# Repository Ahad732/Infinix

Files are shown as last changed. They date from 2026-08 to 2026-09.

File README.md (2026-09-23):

# Infinix
Infinix is a split keyboard that's wireless and runs on bluetooth. It works on a battery which keeps it being portable and being convenient. It also has a RGB underglow which makes it look pretty good. It runs on the ZMK firmware. It can be assembled easily using a simple soldering iron by soldering the XIAO directly on the board and the rest of the diodes and the leds and finally the switches and flashing the firmware, dont forget the batteries and their terminals.

| |Footprint |Value |Quantity |Price |Link |
|---|---|---|---|---|---|
|C1, C2 |CP_Elec_10x10 |1 mF |3 |0.28  |https://robu.in/product/efvm016ada102m10b0-follon-1000uf-25v-10xl10-5mm-aluminum-electrolytic-capacitors-smd-rohs/ |
|D1 - D42  |D_SOD-123 |D |50 |0.5 |https://robu.in/product/sm4007pl-a7-slkor-1a-1kv-1-1v1a-sod-123fl-diodes-general-purpose-rohs/ |
|D43 - D84 |MX_SK6812MINI-E |SK6812MINI-E |51 |5.55  |https://www.etstore.in/products/e9974?variant=48993209319675 |
|R1, R2 |603 |806k |30 |0.12  |https://robu.in/product/0603waf8063t5e-uniohm-royal-ohm-100mw-thick-film-resistors |
|R3, R4 |805 |2M |15 |0.11  |https://robu.in/product/ac0805fr-072ml-yageo-res-thick-film-0805-2m-ohm |
|R5, R6 |1206 |330 |100 |0.13  |https://robu.in/product/1206w4j0331t5e-uniohm-royal-ohm-250mw-thick-film-resistors-200v-%c2%b1100ppm-%e2%84%83-%c2%b15-330%cf%89-1206-chip-resistor-surface-mount-roh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|
|SW1 - SW42|SW_Cherry_MX_1.00u_PCB|SW_Push |1 pack of 45  |11.52 |https://stackskb.com/store/akko-v3-lavender-purple-pro-switch-pack-of-45/ |
|U1, U2 |XIAO-nRF52840-SMD |XIAO-nRF52840-SMD|2 |24.06 |https://www.lioncircuits.com/parts/102010448 |
| |Keycaps |103 Key |1 |10.47 |https://www.amazon.in/gp/product/B0GZMBPHYB/ref=ox_sc_act_title_1?smid=A3S55Z3ML7GNN5&psc=1 |
| |Battery |1500 mAh |2 |9.33  |https://robu.in/product/wly103443-1500mah-3-7v-single-cell-rechargeable-lipo-battery/ |
| | | |Parts Shipping|2.93  | |
| | | |PCB |39.33 | |
| | | |Total |104.33| |

3d-model
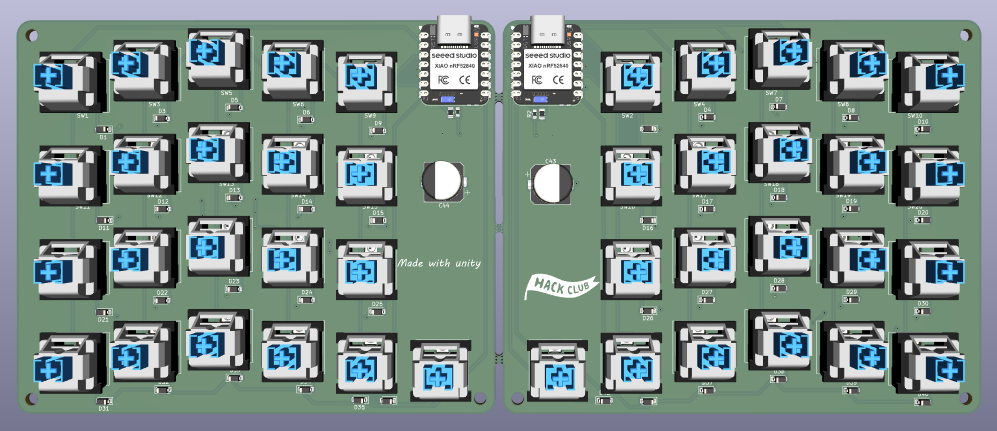
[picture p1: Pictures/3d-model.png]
3d-model
     
PCB
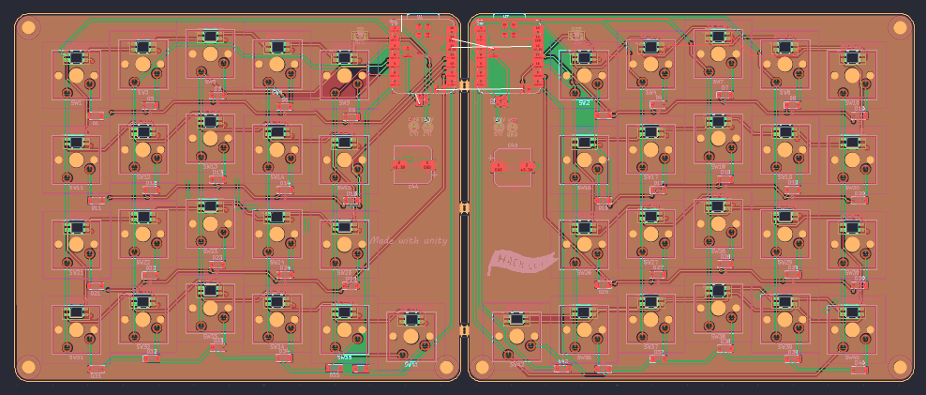
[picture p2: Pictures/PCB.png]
PCB
  
Schematic
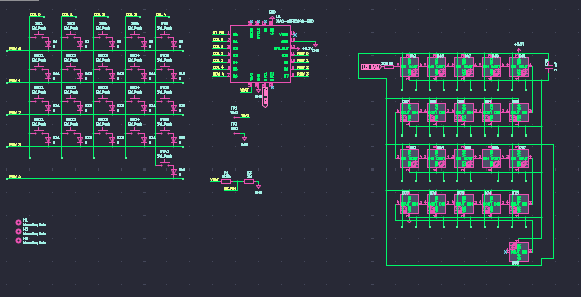
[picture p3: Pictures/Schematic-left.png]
Schematic
  
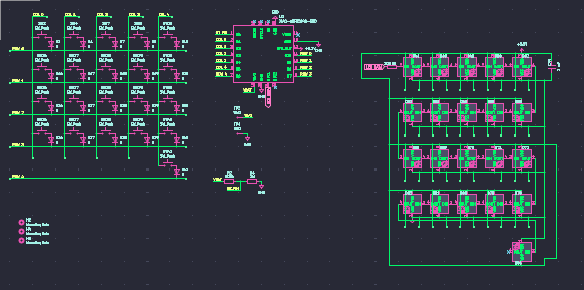
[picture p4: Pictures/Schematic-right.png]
Schematic
  
CAD
CAD
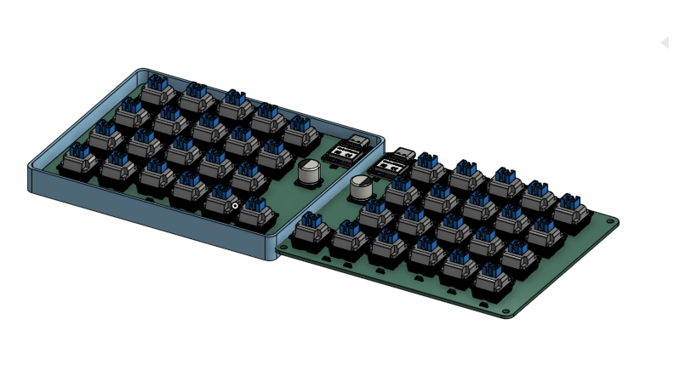
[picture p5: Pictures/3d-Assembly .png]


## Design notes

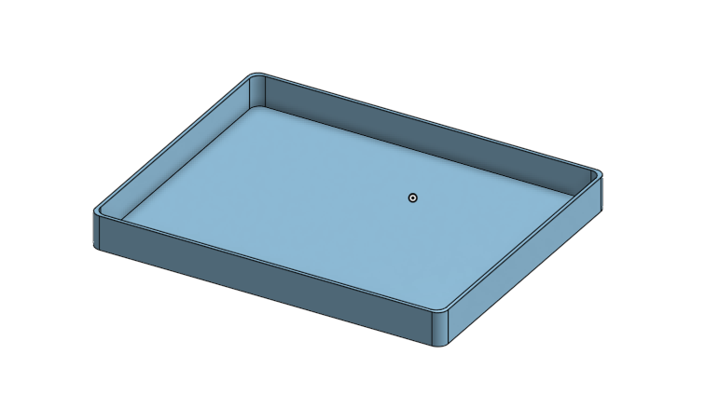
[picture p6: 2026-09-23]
Pictures/Case.png

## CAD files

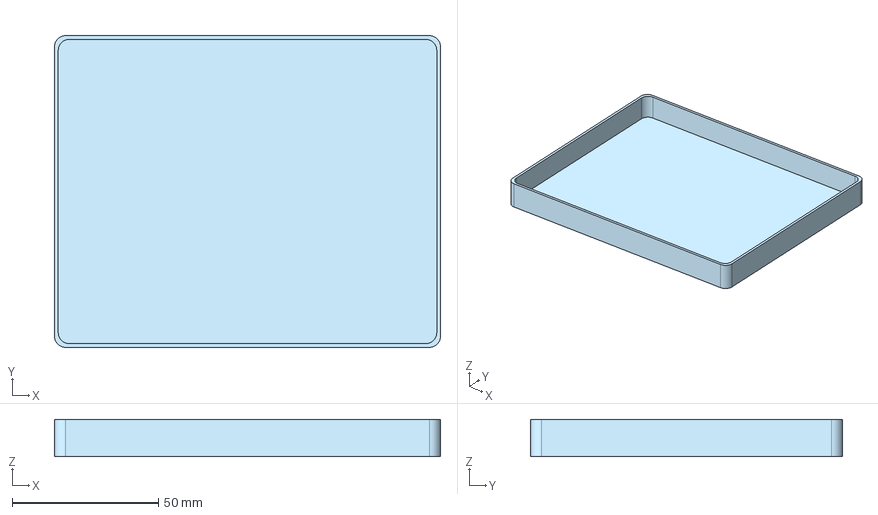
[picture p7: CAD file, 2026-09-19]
CAD/Part Studio 1.step
132.1 x 106.7 x 12.7 mm

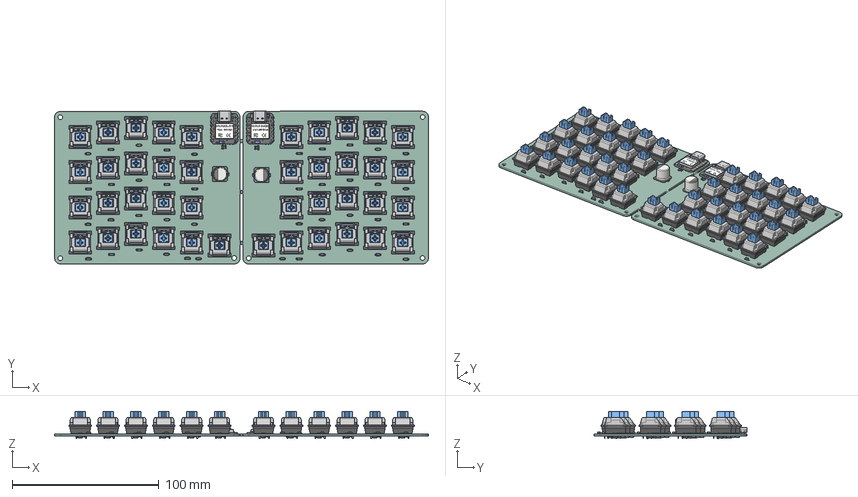
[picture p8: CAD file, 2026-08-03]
CAD/Split Keyboard.step
255.2 x 104.4 x 18.7 mm
Button x 42
Pins x 44
SK6812MINI-E v4 x 42
D_SOD-123 x 42
R_0603_1608Metric x 2
R_0805_2012Metric x 2
CP_Elec_10x10 x 2
BOSS-EXTRUDE14_8_ x 2
BOSS-EXTRUDE7_4_ x 2
BOSS-EXTRUDE7_3_ x 2
BOSS-EXTRUDE14_4_ x 2
BOSS-EXTRUDE14_2_ x 2
BOSS-EXTRUDE14_11_ x 2
BOSS-EXTRUDE7_7_ x 2
BOSS-EXTRUDE14_9_ x 2
BOSS-EXTRUDE14_3_ x 2
BOSS-EXTRUDE14_7_ x 2
MIRROR2 x 2
BOSS-EXTRUDE14_5_ x 2
BOSS-EXTRUDE14_12_ x 2
BOSS-EXTRUDE7_8_ x 2
BOSS-EXTRUDE7_1_ x 2
BOSS-EXTRUDE14_10_ x 2
BOSS-EXTRUDE7_9_ x 2
BOSS-EXTRUDE14_6_ x 2
BOSS-EXTRUDE14_1_ x 2
BOSS-EXTRUDE7_6_ x 2
BOSS-EXTRUDE7_2_ x 2
CUT-EXTRUDE5 x 2
BOSS-EXTRUDE7_5_ x 2
Shield x 2
CAP x 4
ANT1 x 2
Silkscreen x 2
CAP 3 x 2
LED x 2
USR x 2
MSM261D3526H1CPM x 2
R_1206_3216Metric x 2
Split Keyboard_pad
Split Keyboard_PCB

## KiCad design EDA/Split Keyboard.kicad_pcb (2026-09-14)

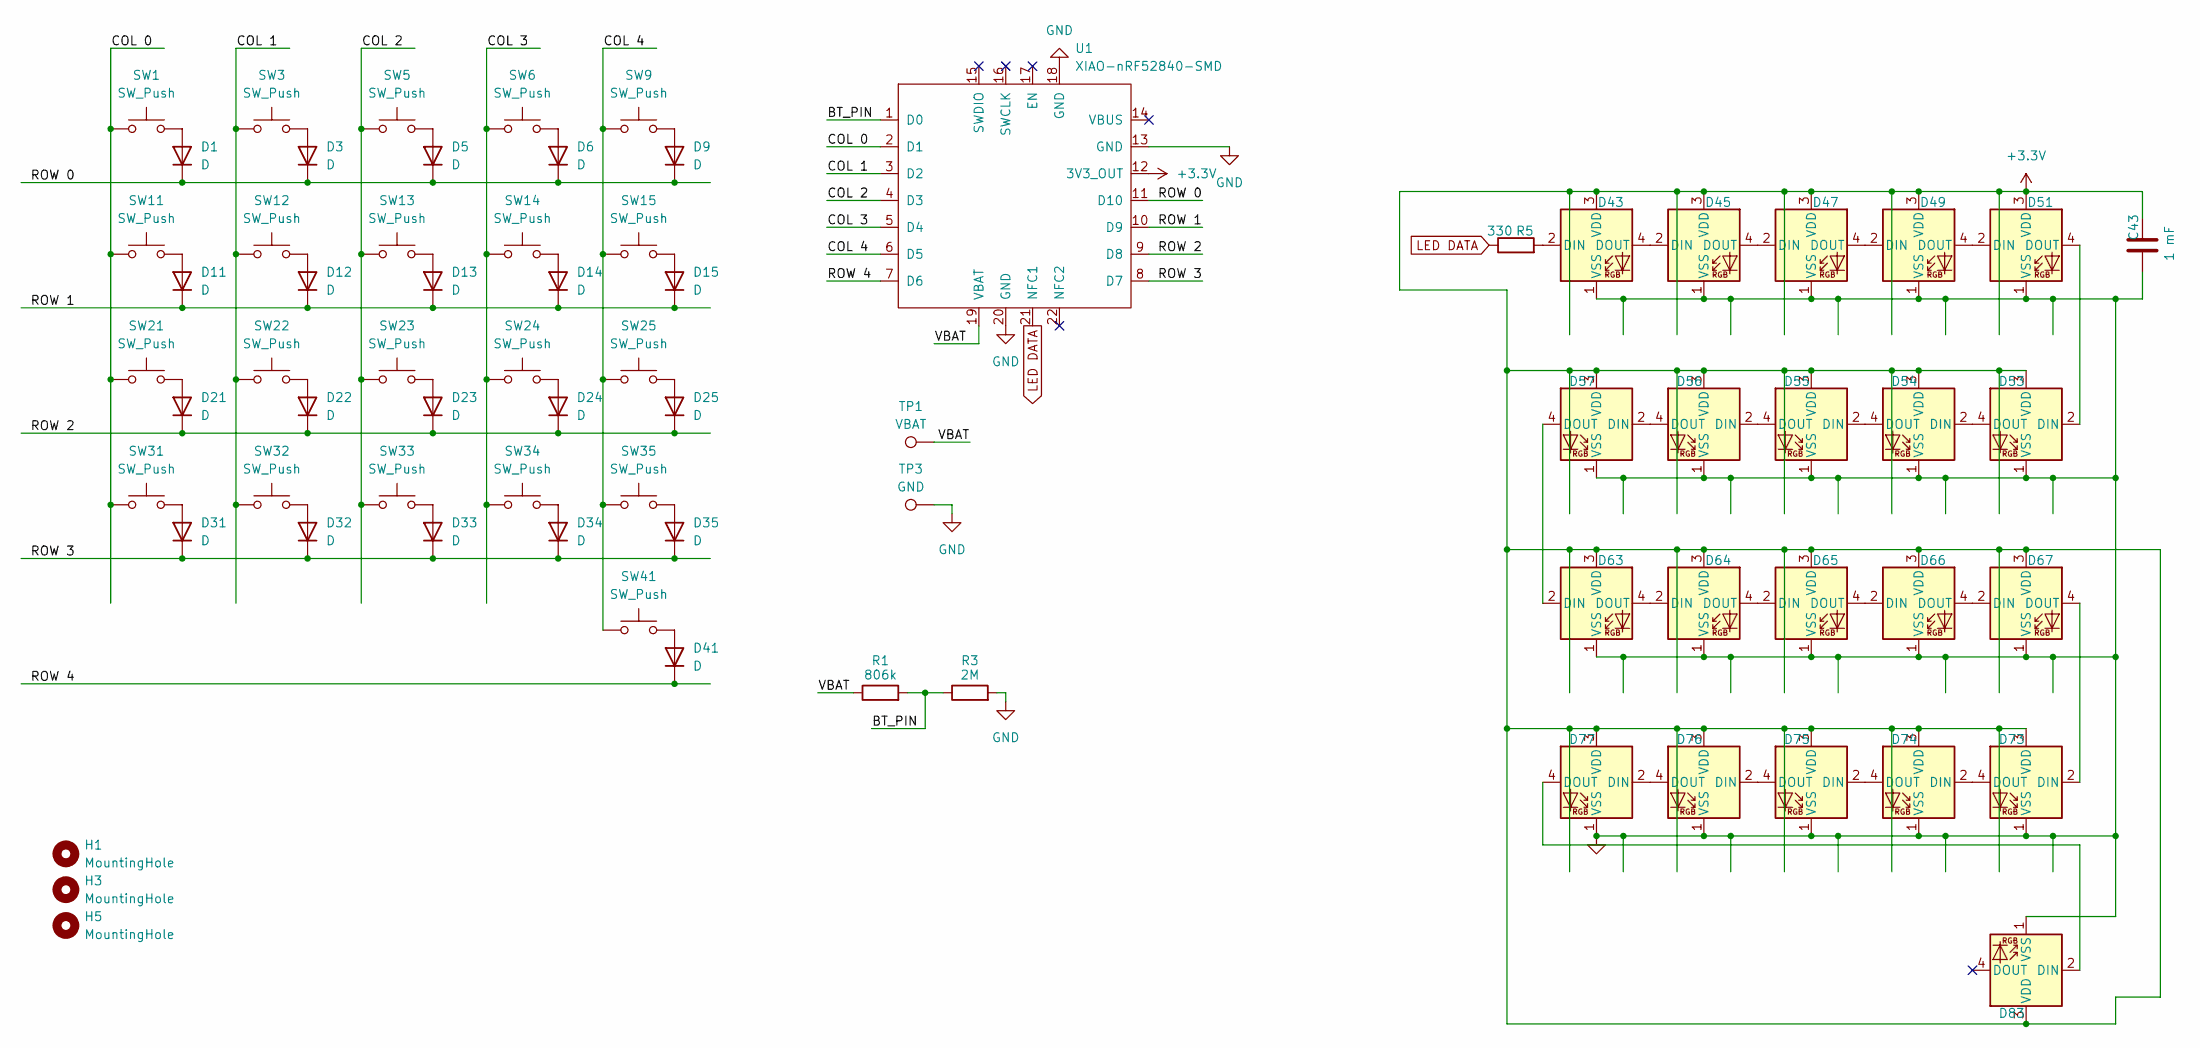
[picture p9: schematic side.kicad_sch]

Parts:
C43: 1 mF; CP_Elec_10x10
D1, D3, D5, D6, D9, D11, D12, D13, D14, D15, D21, D22, D23, D24, D25, D31, D32, D33, D34, D35, D41: D; D_SOD-123
D43, D45, D47, D49, D51, D53, D54, D55, D56, D57, D63, D64, D65, D66, D67, D73, D74, D75, D76, D77, D83: SK6812MINI-E; MX_SK6812MINI-E
H1, H3, H5: MountingHole; MountingHole_3.2mm_M3
R1: 806k; R_0603_1608Metric
R3: 2M; R_0805_2012Metric
R5: 330; R_1206_3216Metric
SW1, SW3, SW5, SW6, SW9, SW11, SW12, SW13, SW14, SW15, SW21, SW22, SW23, SW24, SW25, SW31, SW32, SW33, SW34, SW35, SW41: SW_Push; SW_Cherry_MX_1.00u_PCB
TP1: VBAT; TestPoint_Pad_D2.0mm
TP3: GND; TestPoint_Pad_D2.0mm
U1: XIAO-nRF52840-SMD

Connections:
+3.3V: C43.2, D43.3 (VDD), D45.3 (VDD), D47.3 (VDD), D49.3 (VDD), D51.3 (VDD), D53.3 (VDD), D54.3 (VDD), D55.3 (VDD), D56.3 (VDD), D57.3 (VDD), D63.3 (VDD), D64.3 (VDD), D65.3 (VDD), D66.3 (VDD), D67.3 (VDD), D73.3 (VDD), D74.3 (VDD), D75.3 (VDD), D76.3 (VDD), D77.3 (VDD), D83.3 (VDD), U1.12 (3V3_OUT); also elsewhere on the board
/left/BT_PIN: R1.2, R3.1, U1.1 (D0)
/left/COL 0: SW1.1, SW11.1, SW21.1, SW31.1, U1.2 (D1)
/left/COL 1: SW3.1, SW12.1, SW22.1, SW32.1, U1.3 (D2)
/left/COL 2: SW5.1, SW13.1, SW23.1, SW33.1, U1.4 (D3)
/left/COL 3: SW6.1, SW14.1, SW24.1, SW34.1, U1.5 (D4)
/left/COL 4: SW9.1, SW15.1, SW25.1, SW35.1, SW41.1, U1.6 (D5)
/left/ROW 0: D1.1 (K), D3.1 (K), D5.1 (K), D6.1 (K), D9.1 (K), U1.11 (D10)
/left/ROW 1: D11.1 (K), D12.1 (K), D13.1 (K), D14.1 (K), D15.1 (K), U1.10 (D9)
/left/ROW 2: D21.1 (K), D22.1 (K), D23.1 (K), D24.1 (K), D25.1 (K), U1.9 (D8)
/left/ROW 3: D31.1 (K), D32.1 (K), D33.1 (K), D34.1 (K), D35.1 (K), U1.8 (D7)
/left/ROW 4: D41.1 (K), U1.7 (D6)
/left/VBAT: R1.1, TP1.1 (1_1), U1.19 (VBAT)
GND: C43.1, D43.1 (VSS), D45.1 (VSS), D47.1 (VSS), D49.1 (VSS), D51.1 (VSS), D53.1 (VSS), D54.1 (VSS), D55.1 (VSS), D56.1 (VSS), D57.1 (VSS), D63.1 (VSS), D64.1 (VSS), D65.1 (VSS), D66.1 (VSS), D67.1 (VSS), D73.1 (VSS), D74.1 (VSS), D75.1 (VSS), D76.1 (VSS), D77.1 (VSS), D83.1 (VSS), R3.2, TP3.1 (1_1), U1.13 (GND), U1.18 (GND), U1.20 (GND); also elsewhere on the board
LED DATA: R5.1, U1.21 (NFC1); also elsewhere on the board
unnamed: D1.2 (A), SW1.2
unnamed: D3.2 (A), SW3.2
unnamed: D5.2 (A), SW5.2
unnamed: D6.2 (A), SW6.2
unnamed: D9.2 (A), SW9.2
unnamed: D11.2 (A), SW11.2
unnamed: D12.2 (A), SW12.2
unnamed: D13.2 (A), SW13.2
unnamed: D14.2 (A), SW14.2
unnamed: D15.2 (A), SW15.2
unnamed: D21.2 (A), SW21.2
unnamed: D22.2 (A), SW22.2
unnamed: D23.2 (A), SW23.2
unnamed: D24.2 (A), SW24.2
unnamed: D25.2 (A), SW25.2
unnamed: D31.2 (A), SW31.2
unnamed: D32.2 (A), SW32.2
unnamed: D33.2 (A), SW33.2
unnamed: D34.2 (A), SW34.2
unnamed: D35.2 (A), SW35.2
unnamed: D41.2 (A), SW41.2
unnamed: D43.2 (DIN), R5.2
unnamed: D43.4 (DOUT), D45.2 (DIN)
unnamed: D45.4 (DOUT), D47.2 (DIN)
unnamed: D47.4 (DOUT), D49.2 (DIN)
unnamed: D49.4 (DOUT), D51.2 (DIN)
unnamed: D51.4 (DOUT), D53.2 (DIN)
unnamed: D53.4 (DOUT), D54.2 (DIN)
unnamed: D54.4 (DOUT), D55.2 (DIN)
unnamed: D55.4 (DOUT), D56.2 (DIN)
unnamed: D56.4 (DOUT), D57.2 (DIN)
unnamed: D57.4 (DOUT), D63.2 (DIN)
unnamed: D63.4 (DOUT), D64.2 (DIN)
unnamed: D64.4 (DOUT), D65.2 (DIN)
unnamed: D65.4 (DOUT), D66.2 (DIN)
unnamed: D66.4 (DOUT), D67.2 (DIN)
unnamed: D67.4 (DOUT), D73.2 (DIN)
unnamed: D73.4 (DOUT), D74.2 (DIN)
unnamed: D74.4 (DOUT), D75.2 (DIN)
unnamed: D75.4 (DOUT), D76.2 (DIN)
unnamed: D76.4 (DOUT), D77.2 (DIN)
unnamed: D77.4 (DOUT), D83.2 (DIN)

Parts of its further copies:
C44: 1 mF; CP_Elec_10x10
D2, D4, D7, D8, D10, D16, D17, D18, D19, D20, D26, D27, D28, D29, D30, D36, D37, D38, D39, D40, D42: D; D_SOD-123
D44, D46, D48, D50, D52, D58, D59, D60, D61, D62, D68, D69, D70, D71, D72, D78, D79, D80, D81, D82, D84: SK6812MINI-E; MX_SK6812MINI-E
H2, H6: MountingHole; MountingHole_3.2mm_M3
R2: 806k; R_0603_1608Metric
R4: 2M; R_0805_2012Metric
R6: 330; R_1206_3216Metric
SW2, SW4, SW7, SW8, SW10, SW16, SW17, SW18, SW19, SW20, SW26, SW27, SW28, SW29, SW30, SW36, SW37, SW38, SW39, SW40, SW42: SW_Push; SW_Cherry_MX_1.00u_PCB
TP2: VBAT; TestPoint_Pad_D2.0mm
TP4: GND; TestPoint_Pad_D2.0mm
U2: XIAO-nRF52840-SMD

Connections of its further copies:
+3.3V: C44.2, D44.3 (VDD), D46.3 (VDD), D48.3 (VDD), D50.3 (VDD), D52.3 (VDD), D58.3 (VDD), D59.3 (VDD), D60.3 (VDD), D61.3 (VDD), D62.3 (VDD), D68.3 (VDD), D69.3 (VDD), D70.3 (VDD), D71.3 (VDD), D72.3 (VDD), D78.3 (VDD), D79.3 (VDD), D80.3 (VDD), D81.3 (VDD), D82.3 (VDD), D84.3 (VDD), U2.12 (3V3_OUT); also elsewhere on the board
/right/BT_PIN: R2.2, R4.1, U2.1 (D0)
/right/COL 0: SW2.1, SW16.1, SW26.1, SW36.1, U2.2 (D1)
/right/COL 1: SW4.1, SW17.1, SW27.1, SW37.1, U2.3 (D2)
/right/COL 2: SW7.1, SW18.1, SW28.1, SW38.1, U2.4 (D3)
/right/COL 3: SW8.1, SW19.1, SW29.1, SW39.1, U2.5 (D4)
/right/COL 4: SW10.1, SW20.1, SW30.1, SW40.1, SW42.1, U2.6 (D5)
/right/ROW 0: D2.1 (K), D4.1 (K), D7.1 (K), D8.1 (K), D10.1 (K), U2.11 (D10)
/right/ROW 1: D16.1 (K), D17.1 (K), D18.1 (K), D19.1 (K), D20.1 (K), U2.10 (D9)
/right/ROW 2: D26.1 (K), D27.1 (K), D28.1 (K), D29.1 (K), D30.1 (K), U2.9 (D8)
/right/ROW 3: D36.1 (K), D37.1 (K), D38.1 (K), D39.1 (K), D40.1 (K), U2.8 (D7)
/right/ROW 4: D42.1 (K), U2.7 (D6)
/right/VBAT: R2.1, TP2.1 (1_1), U2.19 (VBAT)
GND: C44.1, D44.1 (VSS), D46.1 (VSS), D48.1 (VSS), D50.1 (VSS), D52.1 (VSS), D58.1 (VSS), D59.1 (VSS), D60.1 (VSS), D61.1 (VSS), D62.1 (VSS), D68.1 (VSS), D69.1 (VSS), D70.1 (VSS), D71.1 (VSS), D72.1 (VSS), D78.1 (VSS), D79.1 (VSS), D80.1 (VSS), D81.1 (VSS), D82.1 (VSS), D84.1 (VSS), R4.2, TP4.1 (1_1), U2.13 (GND), U2.18 (GND), U2.20 (GND); also elsewhere on the board
LED DATA: R6.1, U2.21 (NFC1); also elsewhere on the board
unnamed: D2.2 (A), SW2.2
unnamed: D4.2 (A), SW4.2
unnamed: D7.2 (A), SW7.2
unnamed: D8.2 (A), SW8.2
unnamed: D10.2 (A), SW10.2
unnamed: D16.2 (A), SW16.2
unnamed: D17.2 (A), SW17.2
unnamed: D18.2 (A), SW18.2
unnamed: D19.2 (A), SW19.2
unnamed: D20.2 (A), SW20.2
unnamed: D26.2 (A), SW26.2
unnamed: D27.2 (A), SW27.2
unnamed: D28.2 (A), SW28.2
unnamed: D29.2 (A), SW29.2
unnamed: D30.2 (A), SW30.2
unnamed: D36.2 (A), SW36.2
unnamed: D37.2 (A), SW37.2
unnamed: D38.2 (A), SW38.2
unnamed: D39.2 (A), SW39.2
unnamed: D40.2 (A), SW40.2
unnamed: D42.2 (A), SW42.2
unnamed: D44.2 (DIN), R6.2
unnamed: D44.4 (DOUT), D46.2 (DIN)
unnamed: D46.4 (DOUT), D48.2 (DIN)
unnamed: D48.4 (DOUT), D50.2 (DIN)
unnamed: D50.4 (DOUT), D52.2 (DIN)
unnamed: D52.4 (DOUT), D58.2 (DIN)
unnamed: D58.4 (DOUT), D59.2 (DIN)
unnamed: D59.4 (DOUT), D60.2 (DIN)
unnamed: D60.4 (DOUT), D61.2 (DIN)
unnamed: D61.4 (DOUT), D62.2 (DIN)
unnamed: D62.4 (DOUT), D68.2 (DIN)
unnamed: D68.4 (DOUT), D69.2 (DIN)
unnamed: D69.4 (DOUT), D70.2 (DIN)
unnamed: D70.4 (DOUT), D71.2 (DIN)
unnamed: D71.4 (DOUT), D72.2 (DIN)
unnamed: D72.4 (DOUT), D78.2 (DIN)
unnamed: D78.4 (DOUT), D79.2 (DIN)
unnamed: D79.4 (DOUT), D80.2 (DIN)
unnamed: D80.4 (DOUT), D81.2 (DIN)
unnamed: D81.4 (DOUT), D82.2 (DIN)
unnamed: D82.4 (DOUT), D84.2 (DIN)

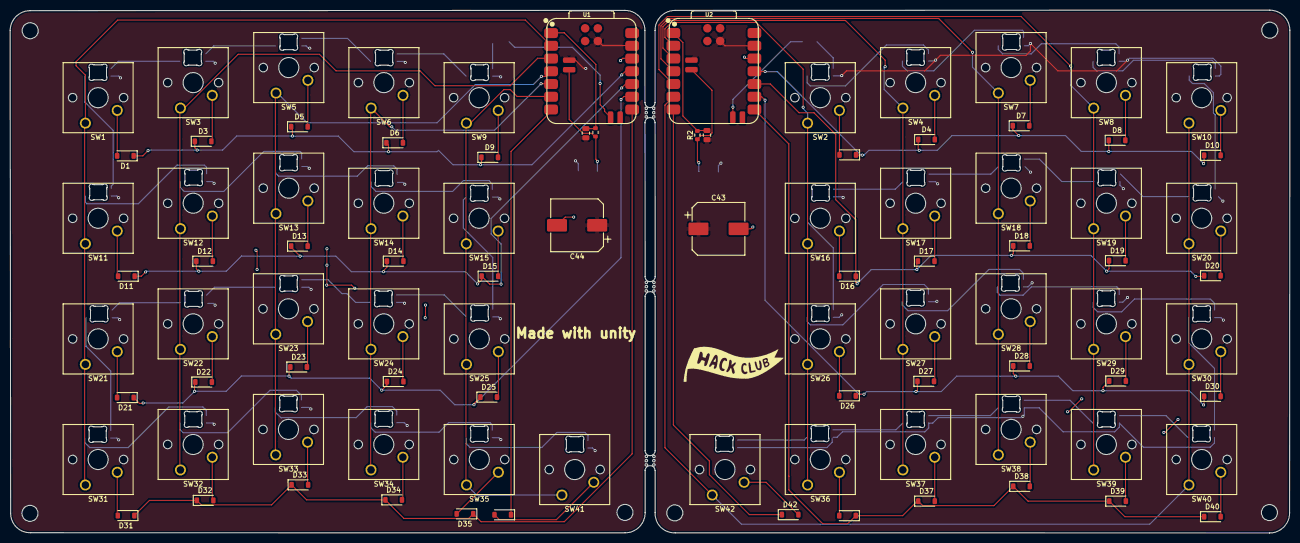
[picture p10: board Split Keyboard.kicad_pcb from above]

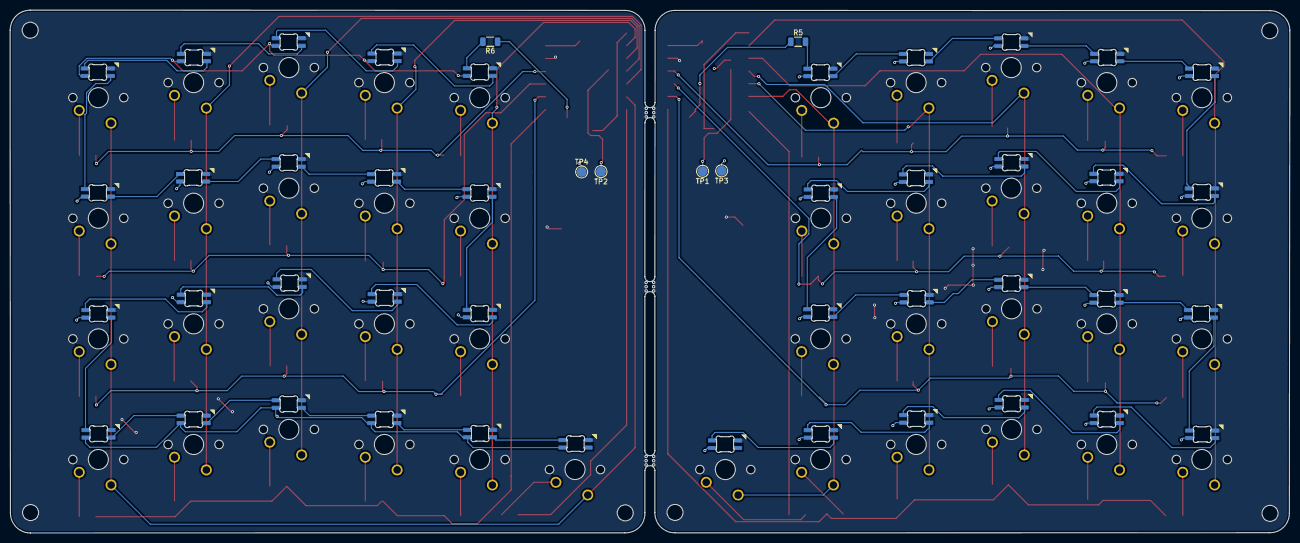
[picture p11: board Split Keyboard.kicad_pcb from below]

Board: 2 copper layers, 255.2 x 104.3 mm, 146 parts (6 on the bottom side), 111 nets.

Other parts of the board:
H5#2, H6#2: MountingHole; MountingHole_3.2mm_M3

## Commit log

2026-07-05 added gerber pictures and bom
    [Split Keyboard-B_Cu.gbr, Split Keyboard-B_Mask.gbr, Split Keyboard-B_Paste.gbr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]
2026-07-05 added new BOM
    [Split Keyboard BOM - bom.csv, bom.csv]
2026-07-12 Add Infinix ZMK shield
    [bom.csv, side.kicad_sch]
2026-08-03 Configure Infinix split keyboard and update files
    [Split Keyboard BOM - bom.csv, Split Keyboard.kicad_pcb, Split Keyboard.step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]
2026-08-05 Relocate shield definition files into config/boards/shields/infinix/
2026-08-05 Force seeeduino_xiao_ble board target for ZMK v0.3
2026-08-05 fix board config
2026-08-05 fix board config(2)
2026-08-05 configure board variant target
2026-08-05 define board compat symbol in shield kconfig
2026-08-09 fix BOM
2026-08-12 new config
    [Split Keyboard-B_Cu.gbr, Split Keyboard-B_Mask.gbr, Split Keyboard-B_Paste.gbr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]
2026-08-12 fix board name to xiao_ble
2026-09-07 added firmware
    [BOM.csv, bom.csv]
2026-09-14 cleaned repo
    [3D model.step, BOM.csv, Split Keyboard case.step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]
2026-09-19 added CAD
    [3D model.step, Part Studio 1.step, Split Keyboard case.step]
2026-09-23 added images of CAD
